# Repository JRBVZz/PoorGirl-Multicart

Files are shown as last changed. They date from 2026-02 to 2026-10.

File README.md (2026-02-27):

### POORGIRL - дешевый картридж-многоигровка для Famicom/Dendy

Данный проект является компиляцией [COOLGIRL](https://github.com/ClusterM/coolgirl-famicom-multicart) **Алексея Clustera** и китайских флэшкартриджей. Допускается установка **EPM570T100** или **EPM240T100**, но учтите, что в EPM240 влезет небольшое количество мапперов из-за малого объема логических ячеек. Картридж поддерживает сохранение только одной игры, если вы запустите другую игру с поддержкой сохранений, то записи от предыдущей игры пропадут.  
  
Характеристики:  
* PRG ROM: max 128 MiB
* CHR RAM: max 256 KiB
* PRG RAM: 32 KiB, FRAM или SRAM с батарейкой

Проект создан в [**KiCad 9**](https://www.kicad.org/).

### Сборка

#### BoM и Schematic
[BoM](PoorGirl-Docs/PoorGirl1.1-BOM.jpg)  
  
[Schematic](PoorGirl-Docs/PoorGirl1.1-Schematic.pdf)

Элементы **R1, D1, C8** нужны только для software reset, по умолчанию в прошивке он отключен.  
Элементы **BT1, D2, D3, R6** нужны для питания SRAM, если предполагается установка FRAM, то достаточно запаять перемычку **"FRAM"**.  
Если вы используете EPM570T100, то замкните две перемычки **"EPM570 ONLY"** на обратной стороне платы.

#### PCB

* Layers: 2
* PCB Thickness: 1.2mm
* Рекомендуется ENIG покрытие
  
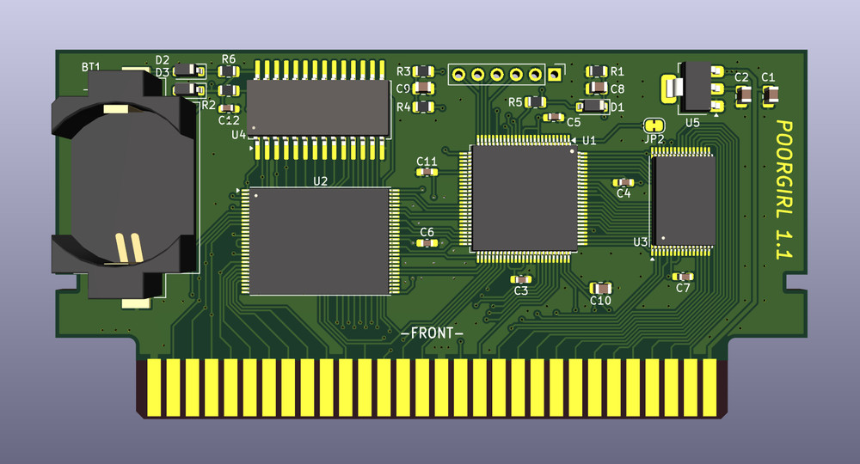
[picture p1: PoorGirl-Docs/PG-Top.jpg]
PG-Top


#### Firmware
В архиве **PoorGirl-Firmware/PoorGirl-Firmware.zip** находятся проекты для Quartus. Все мапперы не влезут в EPM570T100 (тем более в EPM240T100), поэтому выберите нужные в начале файла с verilog кодом **Cool2Poor.v**, чтобы они поместились в 570 (240) логических ячеек.  
По умолчанию reset отключен, поэтому при сбросе приставки появится начальный экран текущей игры, а не меню. Для **включения reset** измените значение `parameter RESET_COMBINATION = 8'b0` на `8'b11010010`, но учтите, что reset занимает около 80 логических ячеек.  
Оптимизированные прошивки можно найти на [форуме Emu-Land.net](https://www.emu-land.net/forum/index.php/topic,82545.0.html), но нужно будет изменить назначения выводов в **Quartus Pin Planner**.

#### Сборка ROM
Для сборки многоигровки с меню можно использовать [COOLGIRL Multirom Builder](https://github.com/ClusterM/coolgirl-multirom-builder). Чтобы работали сохранения, замените файл **saves.asm** на [PoorGirl-Docs/saves.asm](PoorGirl-Docs/saves.asm). Для записи можно использовать [Famicom/NES Dumper/Writer](https://github.com/ClusterM/famicom-dumper-writer), или программатор.

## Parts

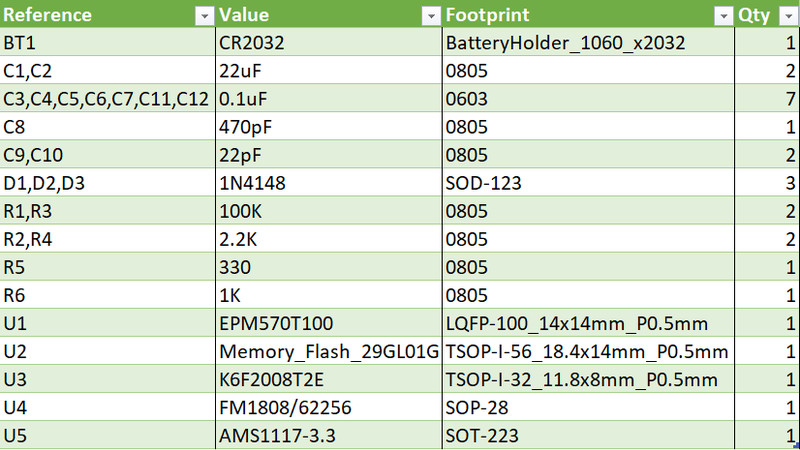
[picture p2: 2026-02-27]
PoorGirl-Docs/PoorGirl1.1-BOM.jpg

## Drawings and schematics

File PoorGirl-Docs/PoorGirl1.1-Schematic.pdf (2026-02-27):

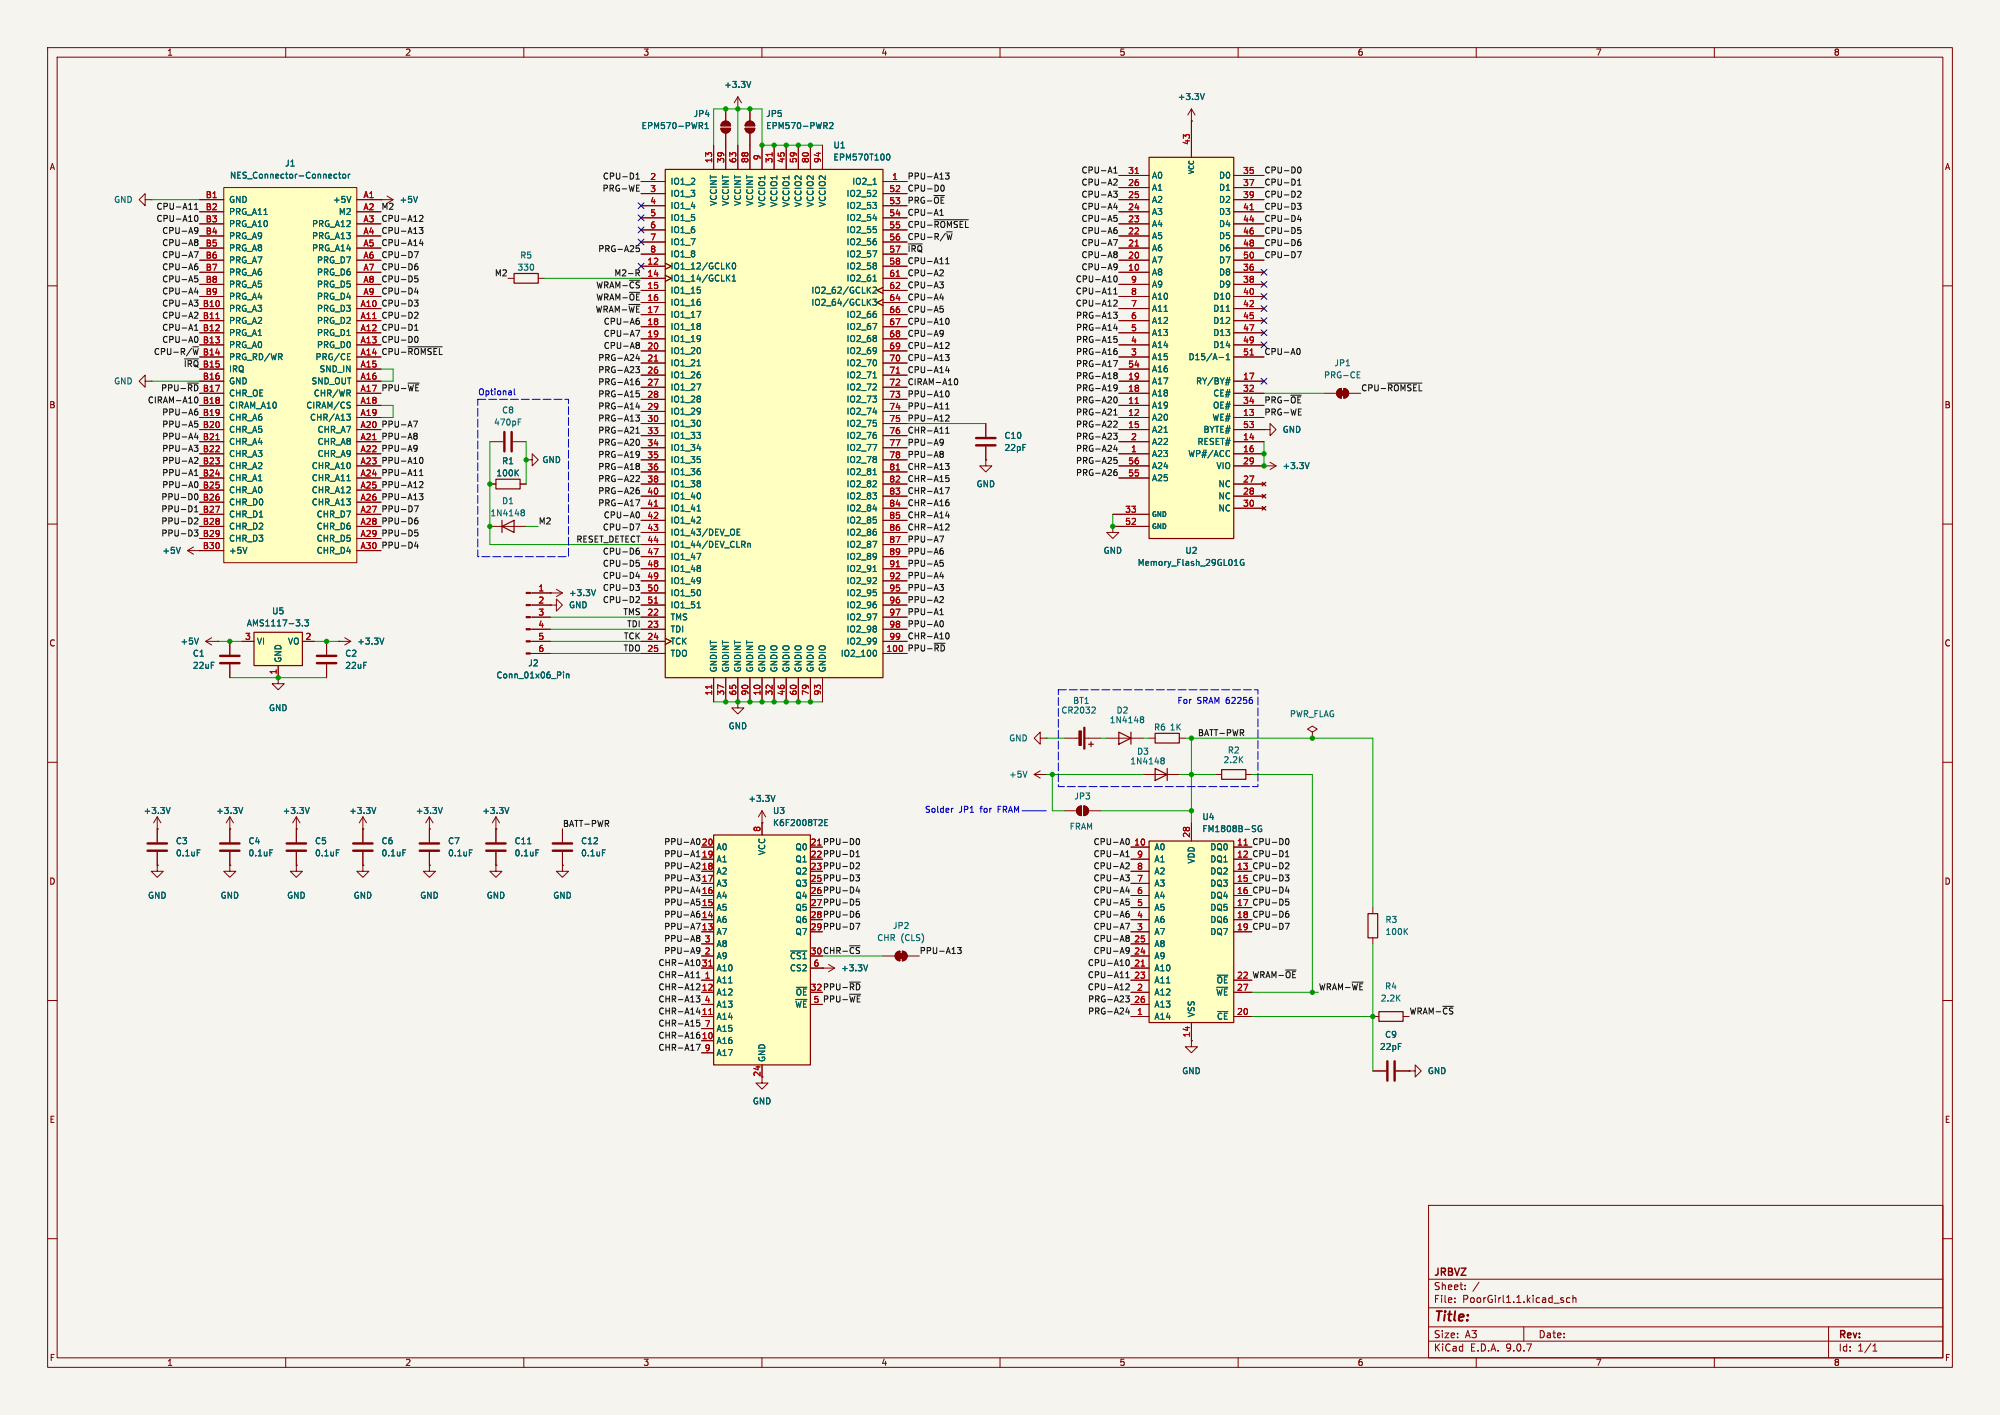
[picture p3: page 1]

CIRAM-A10 CPU-A14 PPU-A10 CPU-D0 CPU-A1 PPU-A13 CPU-~{ROMSEL}
PRG-A13 PRG-A14 PRG-A21 M2-R

PRG-A14 CPU-A12 CPU-A11 PRG-A13 PRG-A16 PRG-A18 PRG-A19 PRG-A15 PRG-A17 CPU-A8 CPU-A9 CPU-A10 CPU-A7 CPU-A6 PRG-A26 PRG-A25 CPU-A10

9 GNDIO 10 VCCIO1 31 GNDIO 32 VCCIO1 45 GNDIO 46 VCCIO2 59 GNDIO 60 VCCIO2 80 GNDIO 79 VCCIO2 94 GNDIO 93

PPU-A0 PPU-A1 PPU-A2 PPU-A9 PPU-A8 PPU-A7 PPU-A6 CHR-A10 PPU-A5 CHR-A11 CHR-A12 CHR-A17 CHR-A13 CHR-A14 CHR-A15 CHR-A16 PPU-A3 BATT-PWR

8 GND 24 A0 20 A1 19 A2 18 A3 17 A4 16 A5 15 A6 14 A7 13 A8 3 A9 2 A10 31 A11 1 A12 12 A13 4 A14 11 A15 7 A16 10 A17 9 Q0 21 Q1 22 Q2 23 Q3 25 Q4 26 Q5 27 Q6 28 Q7 29 ~{CS1}30 CS2 6 ~{OE} 32 ~{WE}5 +3.3V GND

WRAM-~{WE} CPU-D3 CPU-D2 CPU-D4 CPU-D5 CPU-D6

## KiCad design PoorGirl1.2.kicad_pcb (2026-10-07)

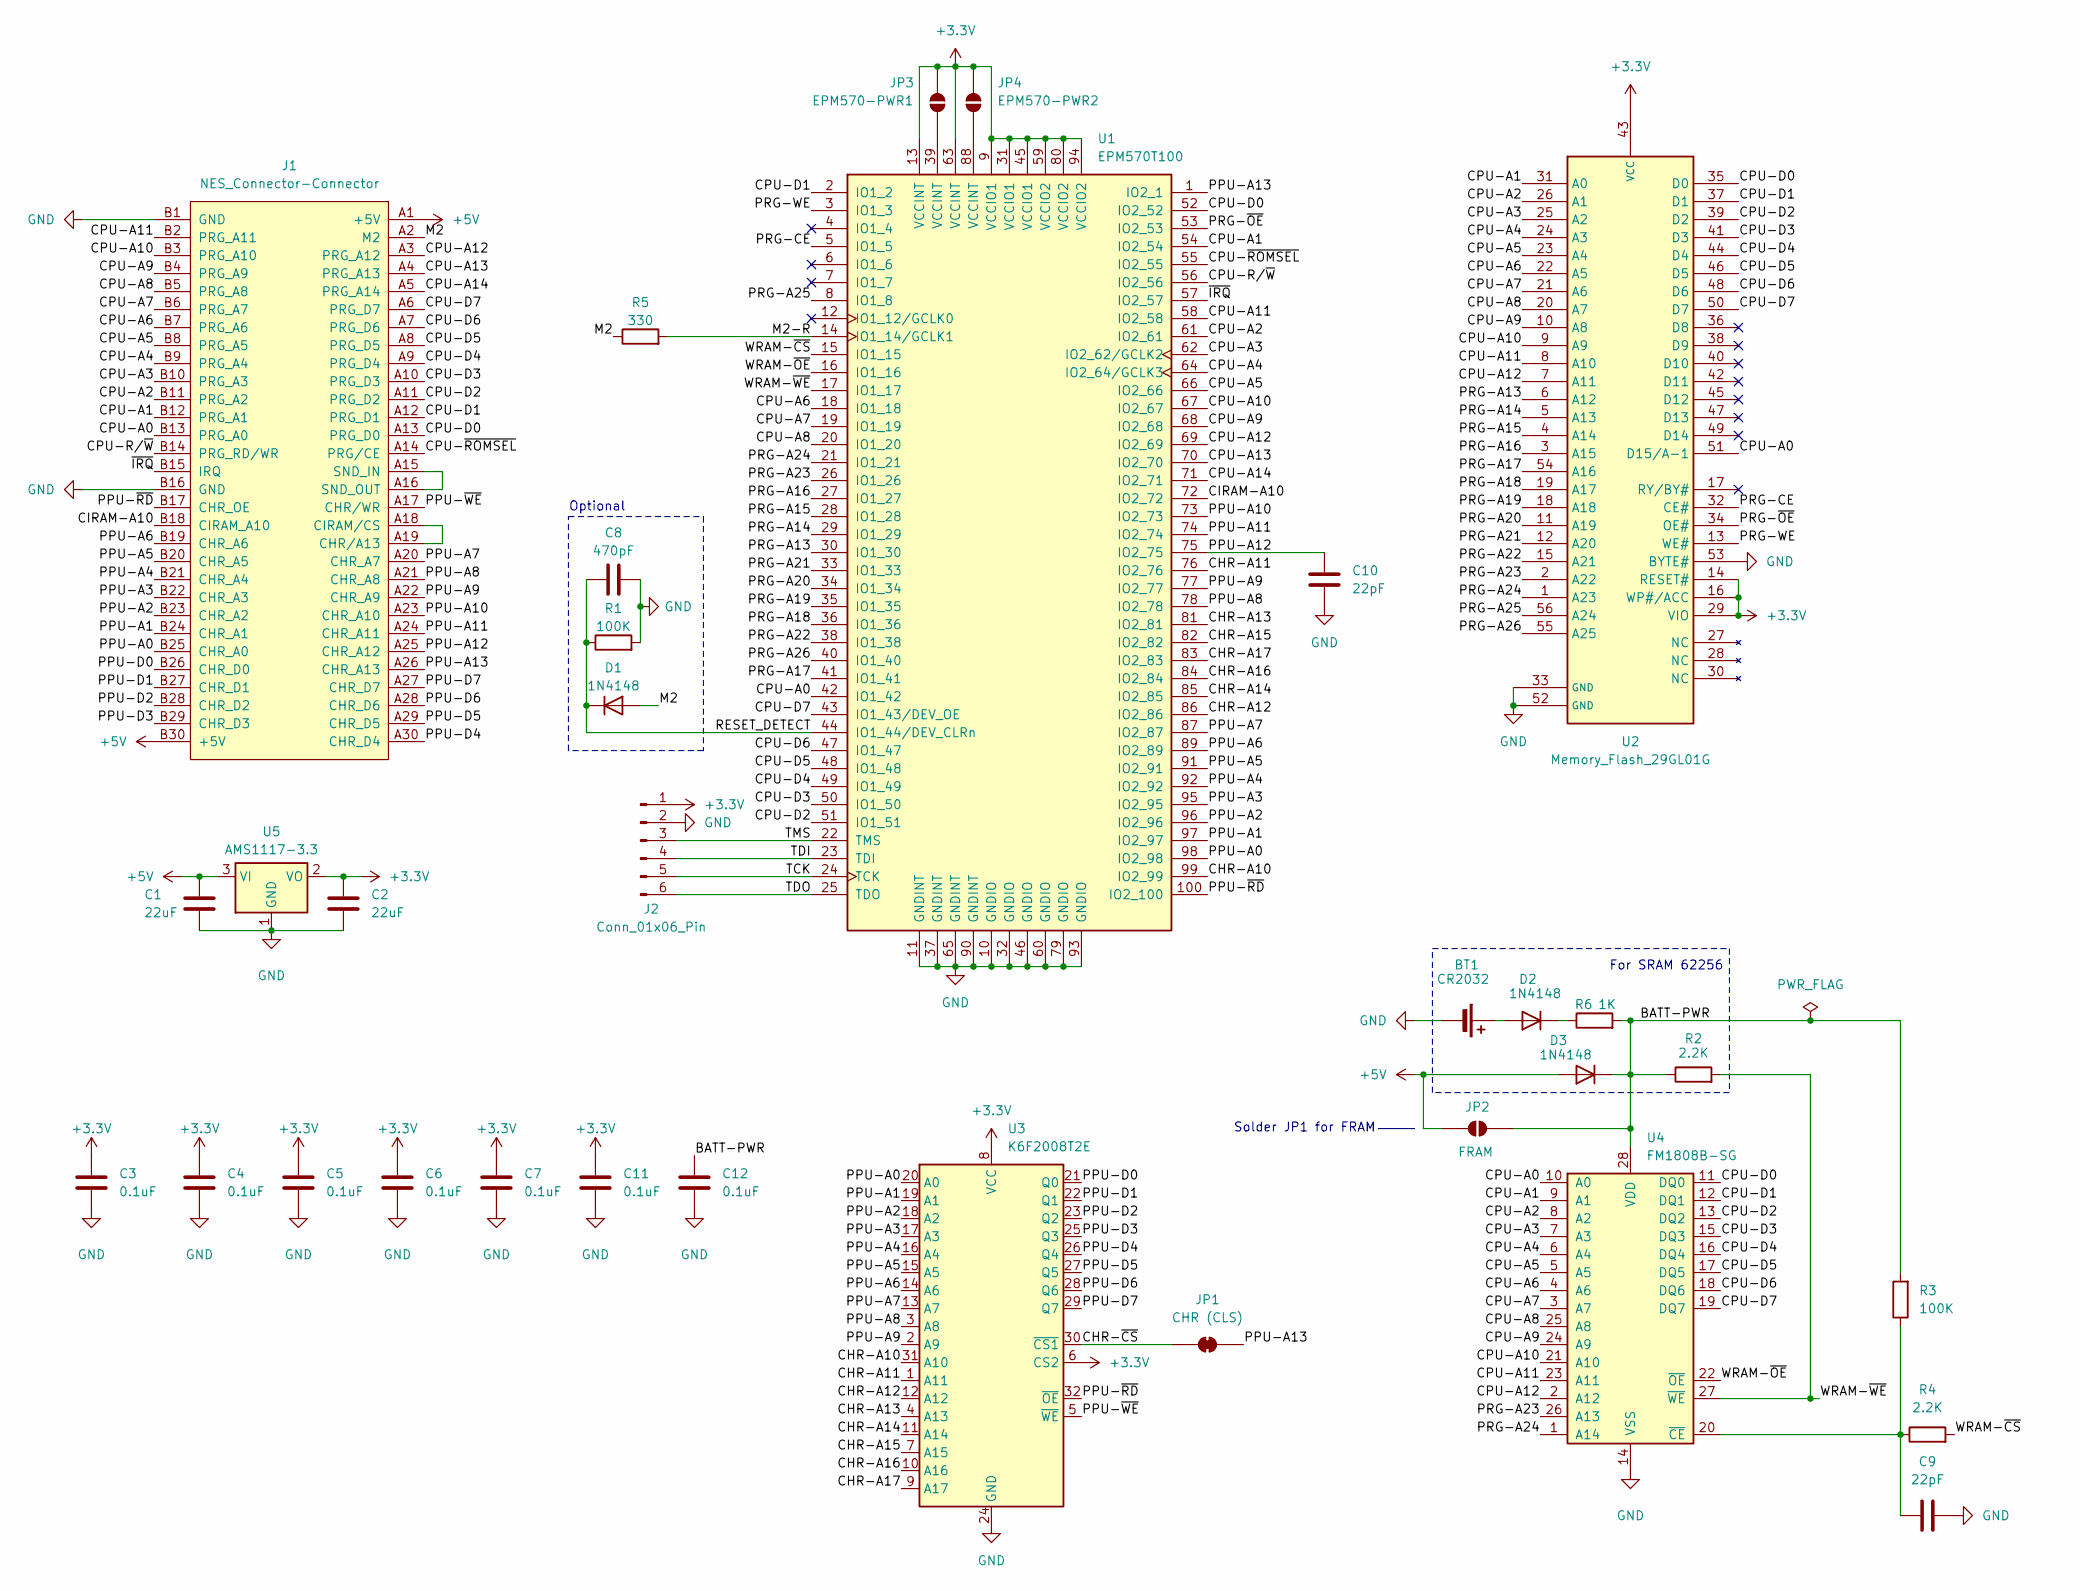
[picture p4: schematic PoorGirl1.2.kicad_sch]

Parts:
BT1: CR2032; BatteryHolder_Keystone_1060_1x2032
C1, C2: 22uF; C_0805_2012Metric
C3, C4, C5, C6, C7, C11, C12: 0.1uF; C_0603_1608Metric_Pad1.08x0.95mm_HandSolder
C8: 470pF; C_0805_2012Metric
C9, C10: 22pF; C_0805_2012Metric
D1, D2, D3: 1N4148; D_SOD-123
J1: NES_Connector-Connector; NES_Connector_L
J2: Conn_01x06_Pin; PinHeader_1x06_P2.54mm_Vertical
JP1: CHR (CLS); SolderJumper-2_P1.3mm_Bridged_RoundedPad1.0x1.5mm
JP2: FRAM; SolderJumper-2_P1.3mm_Open_RoundedPad1.0x1.5mm
JP3: EPM570-PWR1; SolderJumper-2_P1.3mm_Open_RoundedPad1.0x1.5mm
JP4: EPM570-PWR2; SolderJumper-2_P1.3mm_Open_RoundedPad1.0x1.5mm
R1, R3: 100K; R_0805_2012Metric
R2, R4: 2.2K; R_0805_2012Metric
R5: 330; R_0805_2012Metric
R6: 1K; R_0805_2012Metric
U1: EPM570T100; LQFP-100_14x14mm_P0.5mm
U2: Memory_Flash_29GL01G; TSOP-I-56_18.4x14mm_P0.5mm
U3: K6F2008T2E; TSOP-I-32_11.8x8mm_P0.5mm
U4: FM1808B-SG; SOP-28
U5: AMS1117-3.3; SOT-223-3_TabPin2

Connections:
+3.3V: C2.1, C3.1, C4.1, C5.1, C6.1, C7.1, C11.1, J2.1, JP3.2 (B), JP4.2 (B), U1.9 (VCCIO1), U1.13 (VCCINT), U1.31 (VCCIO1), U1.45 (VCCIO1), U1.59 (VCCIO2), U1.63 (VCCINT), U1.80 (VCCIO2), U1.94 (VCCIO2), U2.14 (RESET#), U2.16 (WP#/ACC), U2.29 (VIO), U2.43 (VCC), U3.6 (CS2), U3.8 (VCC), U5.2 (VO)
+5V: C1.1, D3.2 (A), J1.A1 (+5V), J1.B30 (+5V), JP2.1 (A), U5.3 (VI)
/BATT-PWR: C12.1, D3.1 (K), JP2.2 (B), R2.1, R3.2, R6.2, U4.28 (VDD)
/CHR-A10: U1.99 (IO2_99), U3.31 (A10)
/CHR-A11: U1.76 (IO2_76), U3.1 (A11)
/CHR-A12: U1.86 (IO2_86), U3.12 (A12)
/CHR-A13: U1.81 (IO2_81), U3.4 (A13)
/CHR-A14: U1.85 (IO2_85), U3.11 (A14)
/CHR-A15: U1.82 (IO2_82), U3.7 (A15)
/CHR-A16: U1.84 (IO2_84), U3.10 (A16)
/CHR-A17: U1.83 (IO2_83), U3.9 (A17)
/CHR-~CS: JP1.1 (A), U3.30 (~CS1)
/CIRAM-A10: J1.B18 (CIRAM_A10), U1.72 (IO2_72)
/CPU-A0: J1.B13 (PRG_A0), U1.42 (IO1_42), U2.51 (D15/A-1), U4.10 (A0)
/CPU-A1: J1.B12 (PRG_A1), U1.54 (IO2_54), U2.31 (A0), U4.9 (A1)
/CPU-A2: J1.B11 (PRG_A2), U1.61 (IO2_61), U2.26 (A1), U4.8 (A2)
/CPU-A3: J1.B10 (PRG_A3), U1.62 (IO2_62/GCLK2), U2.25 (A2), U4.7 (A3)
/CPU-A4: J1.B9 (PRG_A4), U1.64 (IO2_64/GCLK3), U2.24 (A3), U4.6 (A4)
/CPU-A5: J1.B8 (PRG_A5), U1.66 (IO2_66), U2.23 (A4), U4.5 (A5)
/CPU-A6: J1.B7 (PRG_A6), U1.18 (IO1_18), U2.22 (A5), U4.4 (A6)
/CPU-A7: J1.B6 (PRG_A7), U1.19 (IO1_19), U2.21 (A6), U4.3 (A7)
/CPU-A8: J1.B5 (PRG_A8), U1.20 (IO1_20), U2.20 (A7), U4.25 (A8)
/CPU-A9: J1.B4 (PRG_A9), U1.68 (IO2_68), U2.10 (A8), U4.24 (A9)
/CPU-A10: J1.B3 (PRG_A10), U1.67 (IO2_67), U2.9 (A9), U4.21 (A10)
/CPU-A11: J1.B2 (PRG_A11), U1.58 (IO2_58), U2.8 (A10), U4.23 (A11)
/CPU-A12: J1.A3 (PRG_A12), U1.69 (IO2_69), U2.7 (A11), U4.2 (A12)
/CPU-A13: J1.A4 (PRG_A13), U1.70 (IO2_70)
/CPU-A14: J1.A5 (PRG_A14), U1.71 (IO2_71)
/CPU-D0: J1.A13 (PRG_D0), U1.52 (IO2_52), U2.35 (D0), U4.11 (DQ0)
/CPU-D1: J1.A12 (PRG_D1), U1.2 (IO1_2), U2.37 (D1), U4.12 (DQ1)
/CPU-D2: J1.A11 (PRG_D2), U1.51 (IO1_51), U2.39 (D2), U4.13 (DQ2)
/CPU-D3: J1.A10 (PRG_D3), U1.50 (IO1_50), U2.41 (D3), U4.15 (DQ3)
/CPU-D4: J1.A9 (PRG_D4), U1.49 (IO1_49), U2.44 (D4), U4.16 (DQ4)
/CPU-D5: J1.A8 (PRG_D5), U1.48 (IO1_48), U2.46 (D5), U4.17 (DQ5)
/CPU-D6: J1.A7 (PRG_D6), U1.47 (IO1_47), U2.48 (D6), U4.18 (DQ6)
/CPU-D7: J1.A6 (PRG_D7), U1.43 (IO1_43/DEV_OE), U2.50 (D7), U4.19 (DQ7)
/CPU-R/~W: J1.B14 (PRG_RD/WR), U1.56 (IO2_56)
/CPU-~ROMSEL: J1.A14 (PRG/CE), U1.55 (IO2_55)
/M2: D1.2 (A), J1.A2 (M2), R5.1
/M2-R: R5.2, U1.14 (IO1_14/GCLK1)
/PPU-A0: J1.B25 (CHR_A0), U1.98 (IO2_98), U3.20 (A0)
/PPU-A1: J1.B24 (CHR_A1), U1.97 (IO2_97), U3.19 (A1)
/PPU-A2: J1.B23 (CHR_A2), U1.96 (IO2_96), U3.18 (A2)
/PPU-A3: J1.B22 (CHR_A3), U1.95 (IO2_95), U3.17 (A3)
/PPU-A4: J1.B21 (CHR_A4), U1.92 (IO2_92), U3.16 (A4)
/PPU-A5: J1.B20 (CHR_A5), U1.91 (IO2_91), U3.15 (A5)
/PPU-A6: J1.B19 (CHR_A6), U1.89 (IO2_89), U3.14 (A6)
/PPU-A7: J1.A20 (CHR_A7), U1.87 (IO2_87), U3.13 (A7)
/PPU-A8: J1.A21 (CHR_A8), U1.78 (IO2_78), U3.3 (A8)
/PPU-A9: J1.A22 (CHR_A9), U1.77 (IO2_77), U3.2 (A9)
/PPU-A10: J1.A23 (CHR_A10), U1.73 (IO2_73)
/PPU-A11: J1.A24 (CHR_A11), U1.74 (IO2_74)
/PPU-A12: C10.2, J1.A25 (CHR_A12), U1.75 (IO2_75)
/PPU-A13: J1.A26 (CHR_A13), JP1.2 (B), U1.1 (IO2_1)
/PPU-D0: J1.B26 (CHR_D0), U3.21 (Q0)
/PPU-D1: J1.B27 (CHR_D1), U3.22 (Q1)
/PPU-D2: J1.B28 (CHR_D2), U3.23 (Q2)
/PPU-D3: J1.B29 (CHR_D3), U3.25 (Q3)
/PPU-D4: J1.A30 (CHR_D4), U3.26 (Q4)
/PPU-D5: J1.A29 (CHR_D5), U3.27 (Q5)
/PPU-D6: J1.A28 (CHR_D6), U3.28 (Q6)
/PPU-D7: J1.A27 (CHR_D7), U3.29 (Q7)
/PPU-~RD: J1.B17 (CHR_OE), U1.100 (IO2_100), U3.32 (~OE)
/PPU-~WE: J1.A17 (CHR/WR), U3.5 (~WE)
/PRG-A13: U1.30 (IO1_30), U2.6 (A12)
/PRG-A14: U1.29 (IO1_29), U2.5 (A13)
/PRG-A15: U1.28 (IO1_28), U2.4 (A14)
/PRG-A16: U1.27 (IO1_27), U2.3 (A15)
/PRG-A17: U1.41 (IO1_41), U2.54 (A16)
/PRG-A18: U1.36 (IO1_36), U2.19 (A17)
/PRG-A19: U1.35 (IO1_35), U2.18 (A18)
/PRG-A20: U1.34 (IO1_34), U2.11 (A19)
/PRG-A21: U1.33 (IO1_33), U2.12 (A20)
/PRG-A22: U1.38 (IO1_38), U2.15 (A21)
/PRG-A23: U1.26 (IO1_26), U2.2 (A22), U4.26 (A13)
/PRG-A24: U1.21 (IO1_21), U2.1 (A23), U4.1 (A14)
/PRG-A25: U1.8 (IO1_8), U2.56 (A24)
/PRG-A26: U1.40 (IO1_40), U2.55 (A25)
/PRG-CE: U1.5 (IO1_5), U2.32 (CE#)
/PRG-WE: U1.3 (IO1_3), U2.13 (WE#)
/PRG-~OE: U1.53 (IO2_53), U2.34 (OE#)
/RESET_DETECT: C8.1, D1.1 (K), R1.1, U1.44 (IO1_44/DEV_CLRn)
/TCK: J2.5, U1.24 (TCK)
/TDI: J2.4, U1.23 (TDI)
/TDO: J2.6, U1.25 (TDO)
/TMS: J2.3, U1.22 (TMS)
/WRAM-~CS: R4.2, U1.15 (IO1_15)
/WRAM-~OE: U1.16 (IO1_16), U4.22 (~OE)
/WRAM-~WE: R2.2, U1.17 (IO1_17), U4.27 (~WE)
/~IRQ: J1.B15 (IRQ), U1.57 (IO2_57)
GND: BT1.2 (-), C1.2, C2.2, C3.2, C4.2, C5.2, C6.2, C7.2, C8.2, C9.2, C10.1, C11.2, C12.2, J1.B1 (GND), J1.B16 (GND), J2.2, R1.2, U1.10 (GNDIO), U1.11 (GNDINT), U1.32 (GNDIO), U1.37 (GNDINT), U1.46 (GNDIO), U1.60 (GNDIO), U1.65 (GNDINT), U1.79 (GNDIO), U1.90 (GNDINT), U1.93 (GNDIO), U2.33 (GND), U2.52 (GND), U2.53 (BYTE#), U3.24 (GND), U4.14 (VSS), U5.1 (GND)
unnamed: BT1.1 (+), D2.2 (A)
unnamed: D2.1 (K), R6.1
unnamed: J1.A18 (CIRAM/CS), J1.A19 (CHR/A13)
unnamed: J1.A15 (SND_IN), J1.A16 (SND_OUT)
unnamed: JP3.1 (A), U1.39 (VCCINT)
unnamed: JP4.1 (A), U1.88 (VCCINT)
unnamed: C9.1, R3.1, R4.1, U4.20 (~CE)

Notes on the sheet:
For SRAM 62256
Optional
Solder JP1 for FRAM

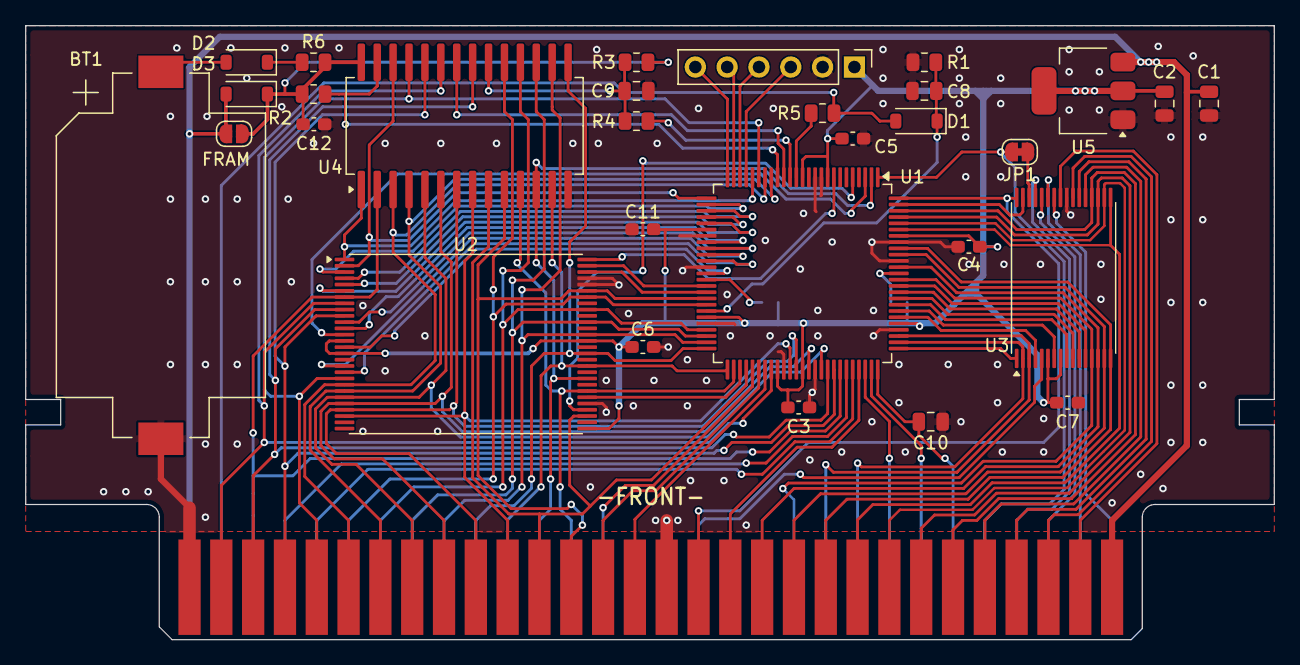
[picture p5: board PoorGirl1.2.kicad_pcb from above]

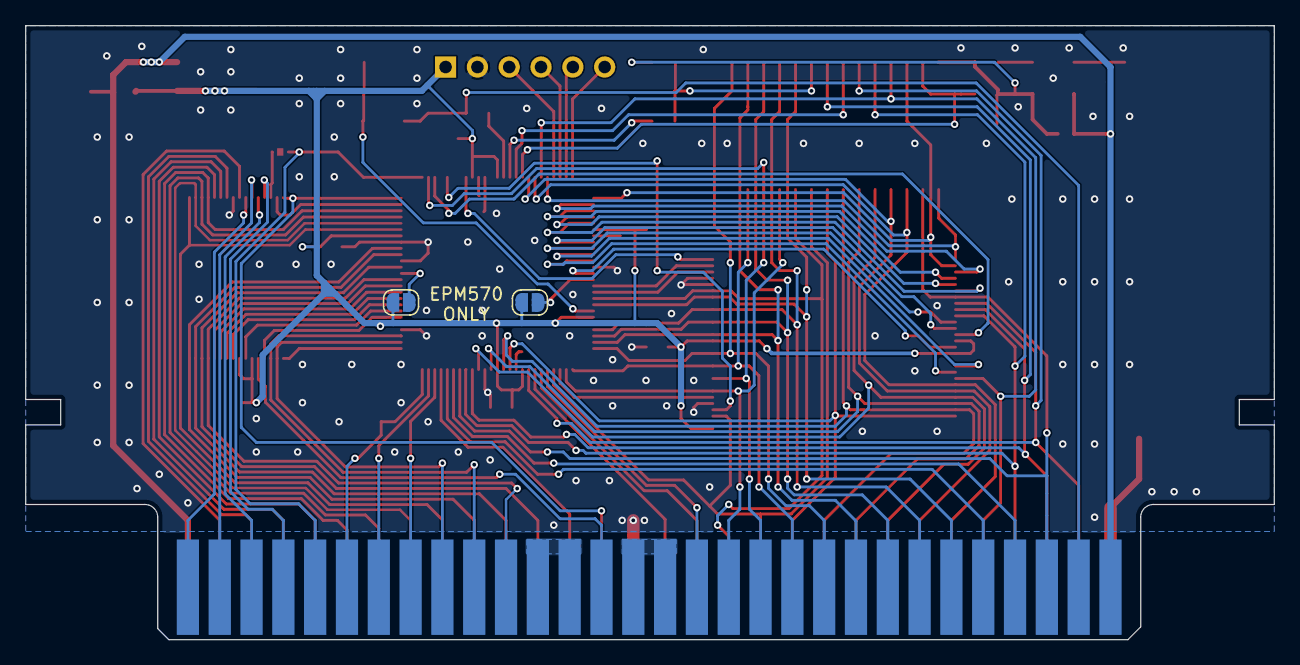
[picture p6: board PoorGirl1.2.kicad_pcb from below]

Board: 2 copper layers, 99.7 x 49.0 mm, 33 parts (2 on the bottom side), 98 nets.
